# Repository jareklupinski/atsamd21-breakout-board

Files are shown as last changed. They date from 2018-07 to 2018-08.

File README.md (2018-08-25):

# atsamd21-breakout-board
A Boilerplate for the ATSAMD21 microcontroller

The ATSAMD21 is one of my favorite microcontroller families. Its low cost and ease of programming made me want to create a board that suits my project needs, so it contains RTC circuitry, an SD card slot, and a few other helpful dev touches.

The board was produced, plugged in, and did not emit magic smoke. All of the functionality hasn't been tested yet.

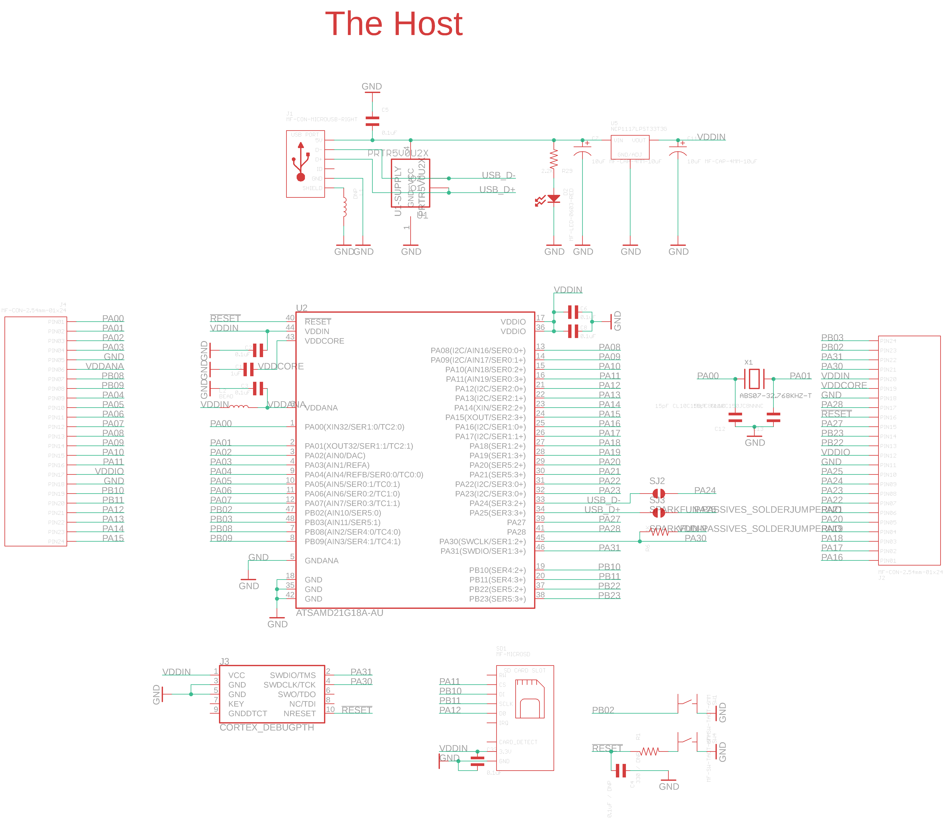
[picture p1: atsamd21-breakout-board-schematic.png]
schematic

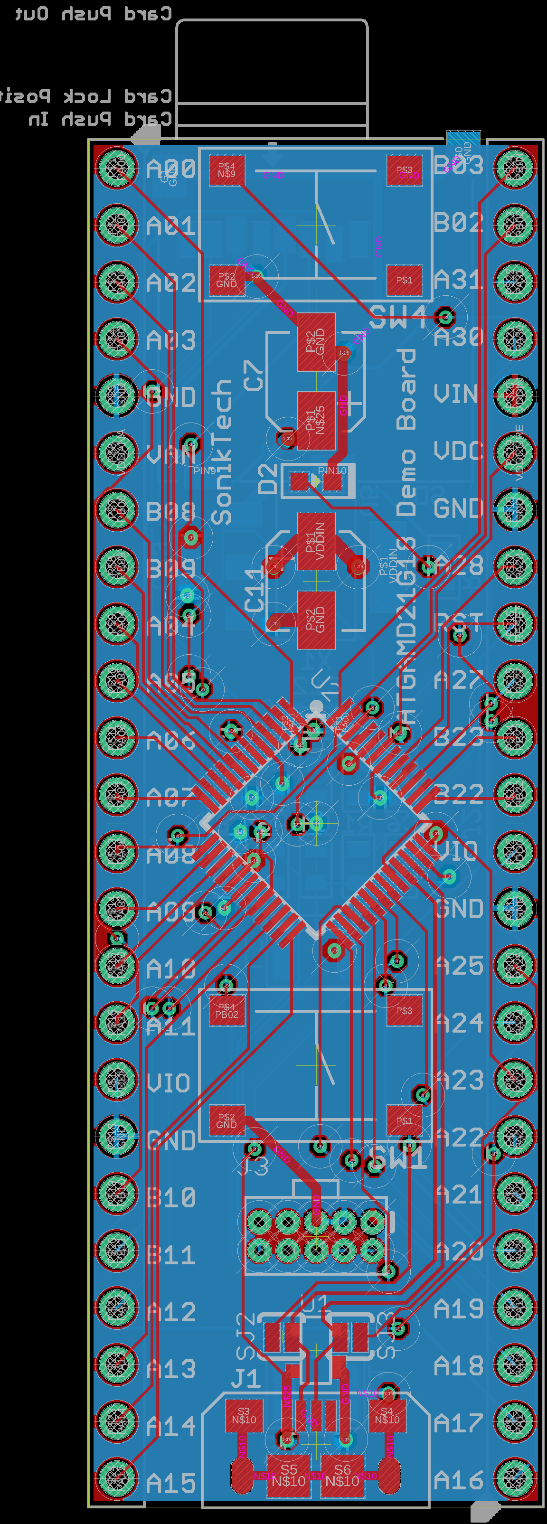
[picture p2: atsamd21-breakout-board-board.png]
board


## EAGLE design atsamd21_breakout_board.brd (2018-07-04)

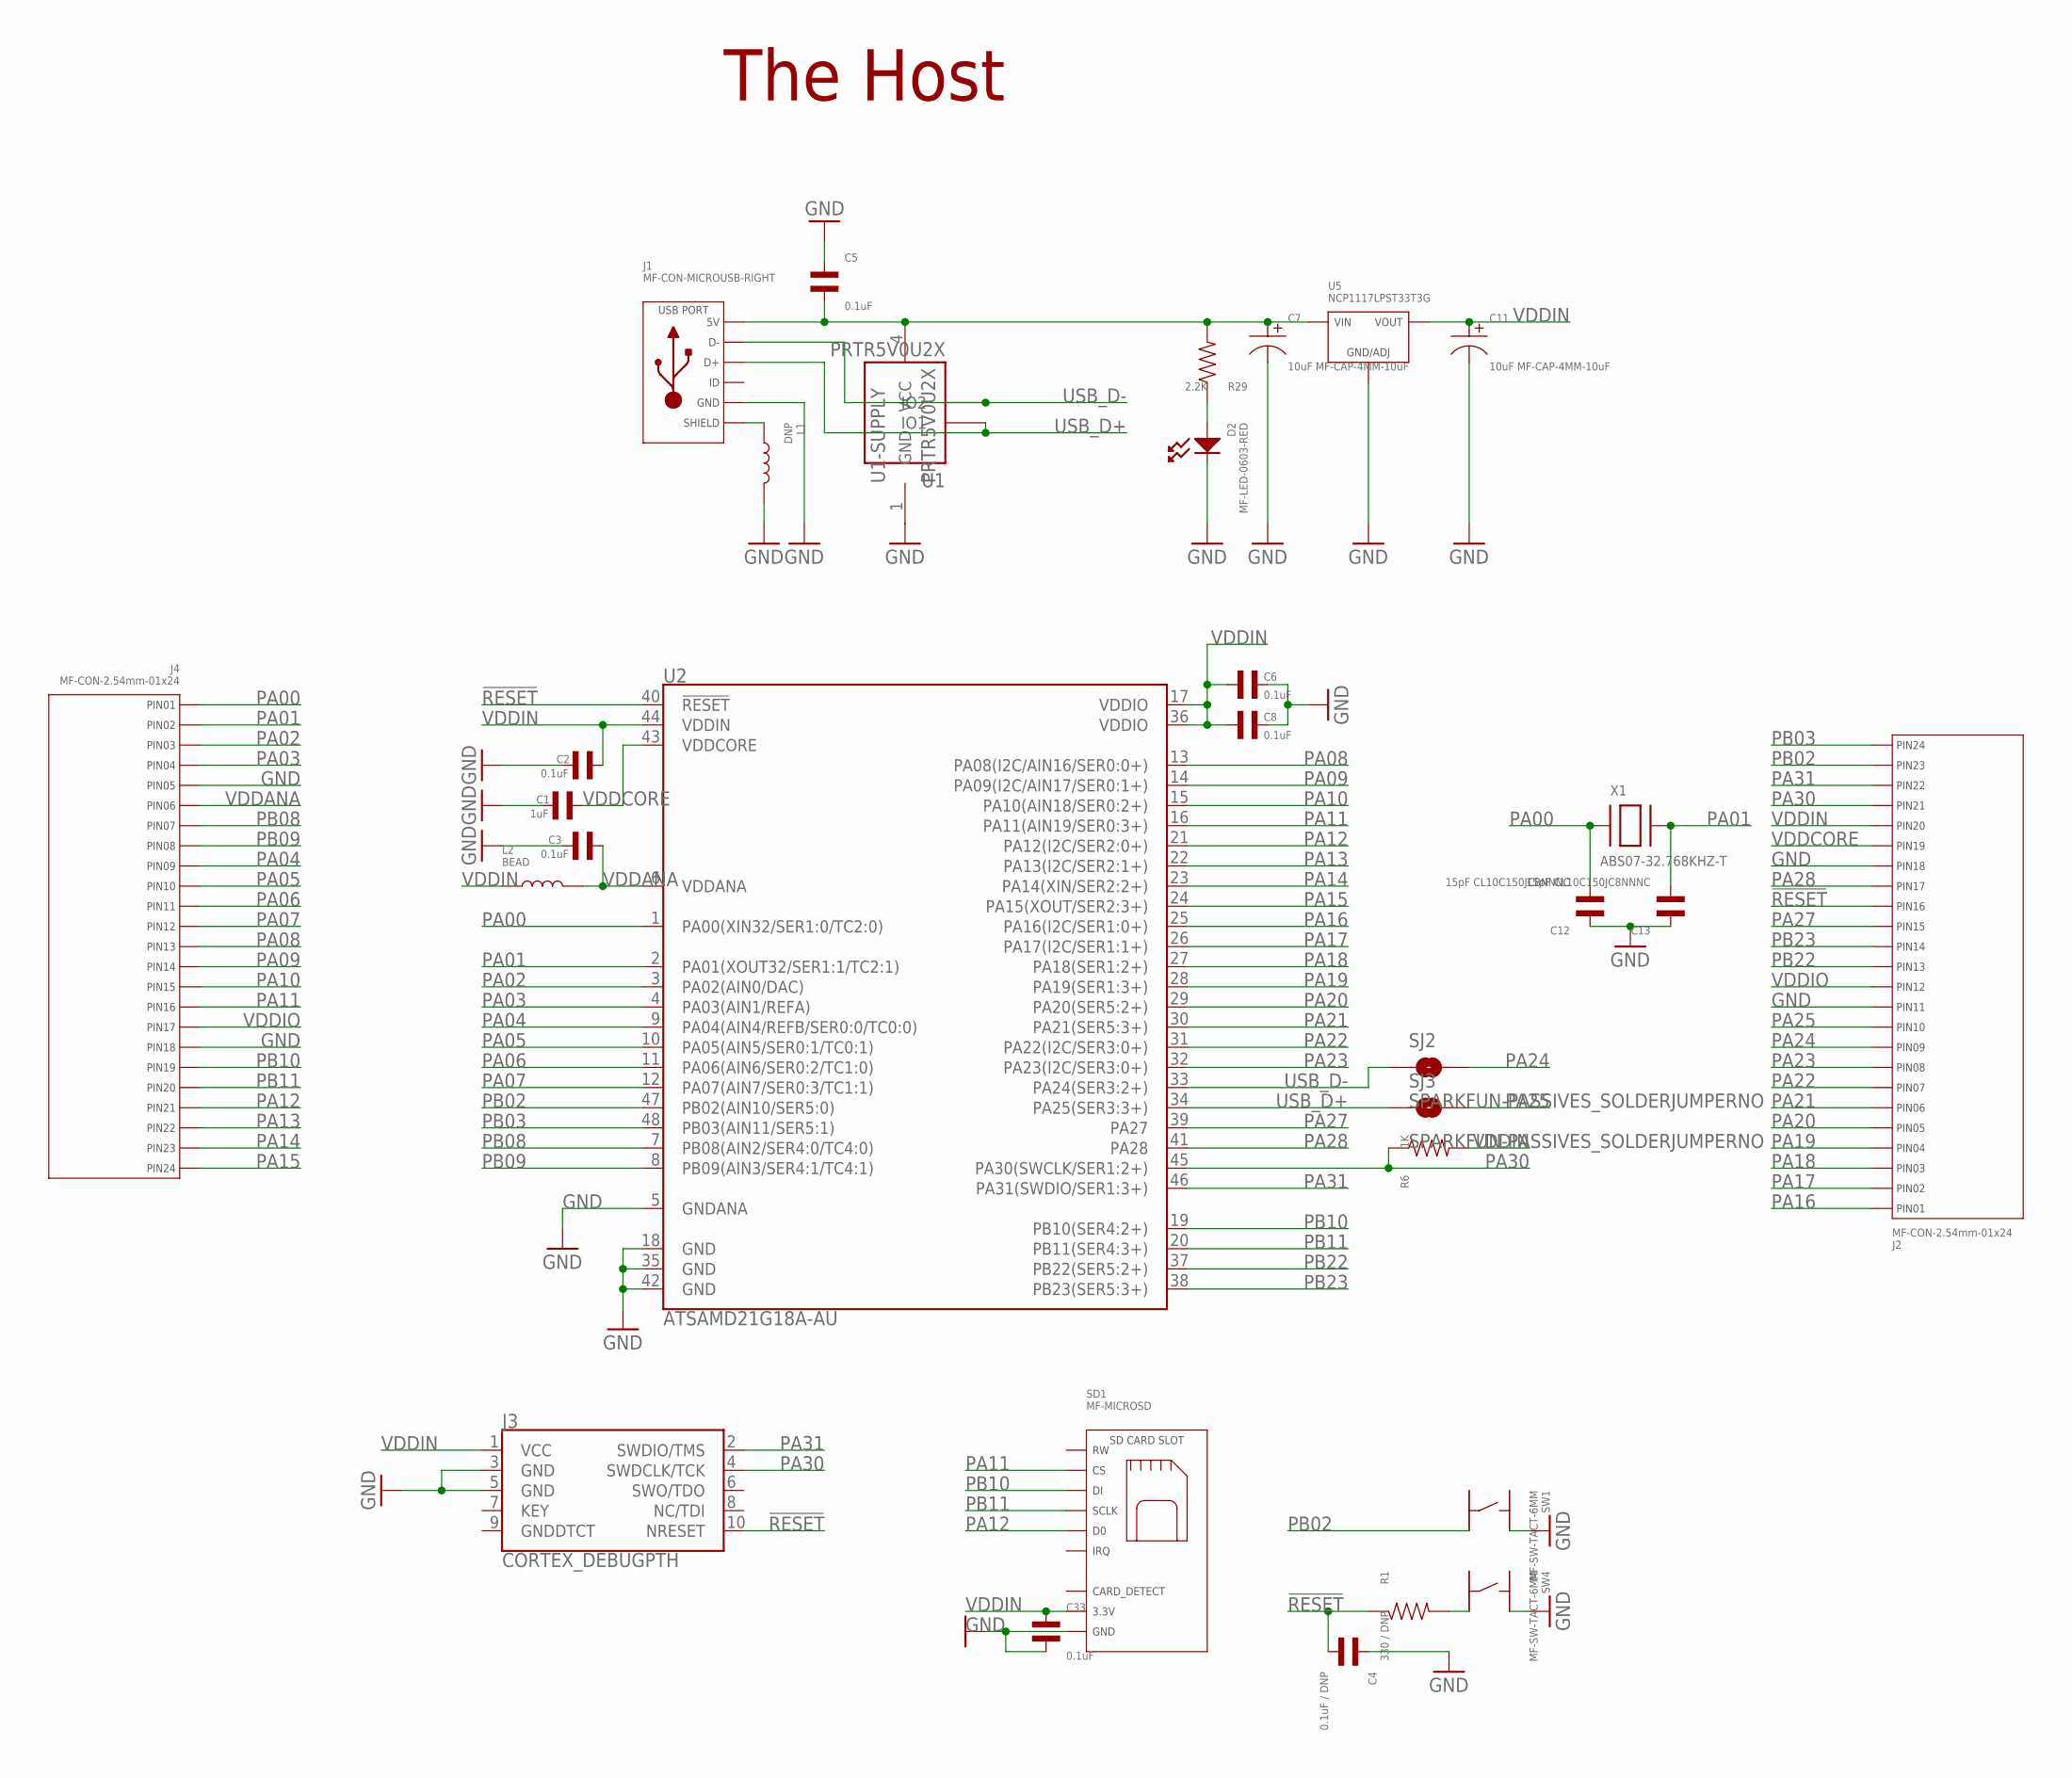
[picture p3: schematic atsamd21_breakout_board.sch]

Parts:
C1: 1uF; C0603
C2, C3, C5, C6, C8, C33: 0.1uF; C0603
C4: 0.1uF / DNP; C0603
C7, C11: 10uF MF-CAP-4MM-10uF; CP4MM
C12, C13: 15pF CL10C150JC8NNNC; C0603
D2: MF-LED-0603-RED; LED0603
J1: MF-CON-MICROUSB-RIGHT; MICROUSB-RIGHT
J2, J4: MF-CON-2.54mm-01x24; PTH_2.54MM_01X24
J3: CORTEX_DEBUGPTH; 2X5-PTH-1.27MM
L1: DNP; L1210
L2: BEAD; L1210
R1: 330 / DNP; R0603
R6: 1K; R0603
R29: 2.2K; R0603
SD1: MF-MICROSD
SJ2, SJ3: SPARKFUN-PASSIVES_SOLDERJUMPERNO; SPARKFUN-PASSIVES_SJ_2S-NO
SW1, SW4: MF-SW-TACT-6MM; TACT6MM
U1: PRTR5V0U2X; SOT-143B
U2: ATSAMD21G18A-AU; TQFP-48
U5: NCP1117LPST33T3G; SOT-223-3
X1: ABS07-32.768KHZ-T; XTAL3215

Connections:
!RESET: C4.P$2, J2.P$16 (PIN16), J3.10 (NRESET), R1.P$1, U2.40 (!RESET!)
GND: C1.P$2, C2.P$1, C3.P$1, C4.P$1, C5.P$1, C6.P$1, C7.P$2, C8.P$1, C11.P$2, C12.P$1, C13.P$1, C33.P$2, D2.CATHODE, J1.5 (GND), J2.P$11 (PIN11), J2.P$18 (PIN18), J3.3 (GND), J3.5 (GND), J4.P$5 (PIN5), J4.P$18 (PIN18), L1.P$2, SD1.G0 (GND), SD1.G1 (GND), SD1.PIN6 (GND), SW1.P$2, SW4.P$2, U1.1 (GND), U2.5 (GNDANA), U2.18 (GND), U2.35 (GND), U2.42 (GND), U5.P$2 (GND/ADJ)
unnamed: R1.P$2, SW4.P$4
unnamed: J1.S1 (SLD), J1.S2 (SLD), J1.S3 (SLD), J1.S4 (SLD), J1.S5 (SLD), J1.S6 (SLD), L1.P$1
unnamed: D2.ANODE, R29.P$1
unnamed: C5.P$2, C7.P$1, J1.1 (5V), R29.P$2, U1.4 (VCC), U5.P$4 (VIN)
PA00: C12.P$2, J4.P$1 (PIN1), U2.1 (PA00(XIN32/SER1:0/TC2:0)), X1.P$1
PA01: C13.P$2, J4.P$2 (PIN2), U2.2 (PA01(XOUT32/SER1:1/TC2:1)), X1.P$2
PA02: J4.P$3 (PIN3), U2.3 (PA02(AIN0/DAC))
PA03: J4.P$4 (PIN4), U2.4 (PA03(AIN1/REFA))
PA04: J4.P$9 (PIN9), U2.9 (PA04(AIN4/REFB/SER0:0/TC0:0))
PA05: J4.P$10 (PIN10), U2.10 (PA05(AIN5/SER0:1/TC0:1))
PA06: J4.P$11 (PIN11), U2.11 (PA06(AIN6/SER0:2/TC1:0))
PA07: J4.P$12 (PIN12), U2.12 (PA07(AIN7/SER0:3/TC1:1))
PA08: J4.P$13 (PIN13), U2.13 (PA08(I2C/AIN16/SER0:0+))
PA09: J4.P$14 (PIN14), U2.14 (PA09(I2C/AIN17/SER0:1+))
PA10: J4.P$15 (PIN15), U2.15 (PA10(AIN18/SER0:2+))
PA11: J4.P$16 (PIN16), SD1.PIN2 (CS), U2.16 (PA11(AIN19/SER0:3+))
PA12: J4.P$21 (PIN21), SD1.PIN7 (D0), U2.21 (PA12(I2C/SER2:0+))
PA13: J4.P$22 (PIN22), U2.22 (PA13(I2C/SER2:1+))
PA14: J4.P$23 (PIN23), U2.23 (PA14(XIN/SER2:2+))
PA15: J4.P$24 (PIN24), U2.24 (PA15(XOUT/SER2:3+))
PA16: J2.P$1 (PIN1), U2.25 (PA16(I2C/SER1:0+))
PA17: J2.P$2 (PIN2), U2.26 (PA17(I2C/SER1:1+))
PA18: J2.P$3 (PIN3), U2.27 (PA18(SER1:2+))
PA19: J2.P$4 (PIN4), U2.28 (PA19(SER1:3+))
PA20: J2.P$5 (PIN5), U2.29 (PA20(SER5:2+))
PA21: J2.P$6 (PIN6), U2.30 (PA21(SER5:3+))
PA22: J2.P$7 (PIN7), U2.31 (PA22(I2C/SER3:0+))
PA23: J2.P$8 (PIN8), U2.32 (PA23(I2C/SER3:0+))
PA24: J2.P$9 (PIN9), SJ2.2
PA25: J2.P$10 (PIN10), SJ3.2
PA27: J2.P$15 (PIN15), U2.39 (PA27)
PA28: J2.P$17 (PIN17), U2.41 (PA28)
PA30: J2.P$21 (PIN21), J3.4 (SWDCLK/TCK), R6.P$1, U2.45 (PA30(SWCLK/SER1:2+))
PA31: J2.P$22 (PIN22), J3.2 (SWDIO/TMS), U2.46 (PA31(SWDIO/SER1:3+))
PB02: J2.P$23 (PIN23), SW1.P$4, U2.47 (PB02(AIN10/SER5:0))
PB03: J2.P$24 (PIN24), U2.48 (PB03(AIN11/SER5:1))
PB08: J4.P$7 (PIN7), U2.7 (PB08(AIN2/SER4:0/TC4:0))
PB09: J4.P$8 (PIN8), U2.8 (PB09(AIN3/SER4:1/TC4:1))
PB10: J4.P$19 (PIN19), SD1.PIN3 (DI), U2.19 (PB10(SER4:2+))
PB11: J4.P$20 (PIN20), SD1.PIN5 (SCLK), U2.20 (PB11(SER4:3+))
PB22: J2.P$13 (PIN13), U2.37 (PB22(SER5:2+))
PB23: J2.P$14 (PIN14), U2.38 (PB23(SER5:3+))
USB_D+: J1.3 (D+), SJ3.1, U1.2 (IO1), U2.34 (PA25(SER3:3+))
USB_D-: J1.2 (D-), SJ2.1, U1.3 (IO2), U2.33 (PA24(SER3:2+))
VDDANA: C3.P$2, J4.P$6 (PIN6), L2.P$2, U2.6 (VDDANA)
VDDCORE: C1.P$1, J2.P$19 (PIN19), U2.43 (VDDCORE)
VDDIN: C2.P$2, C6.P$2, C8.P$2, C11.P$1, C33.P$1, J2.P$20 (PIN20), J3.1 (VCC), L2.P$1, R6.P$2, SD1.PIN4 (3.3V), U2.17 (VDDIO), U2.36 (VDDIO), U2.44 (VDDIN), U5.P$1 (VOUT), U5.P$3 (VOUT)
VDDIO: J2.P$12 (PIN12), J4.P$17 (PIN17)

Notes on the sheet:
The Host

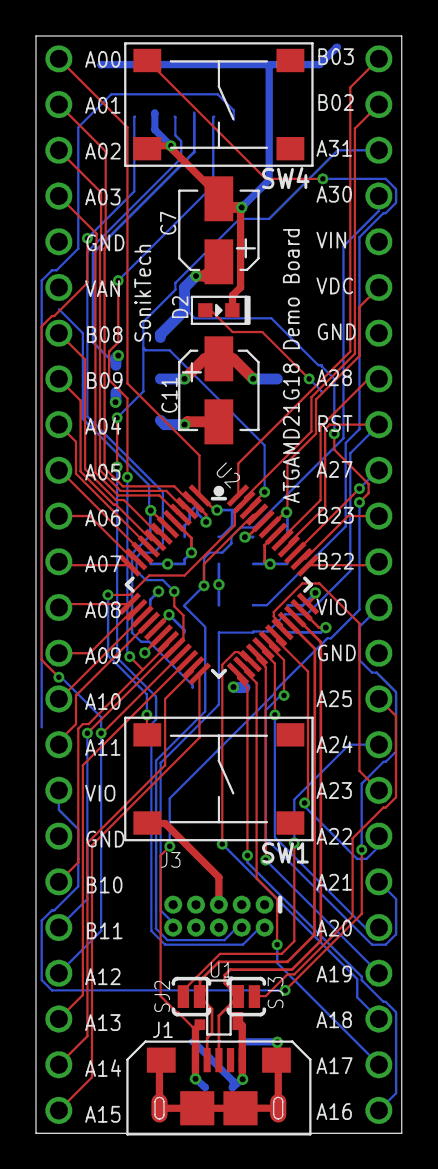
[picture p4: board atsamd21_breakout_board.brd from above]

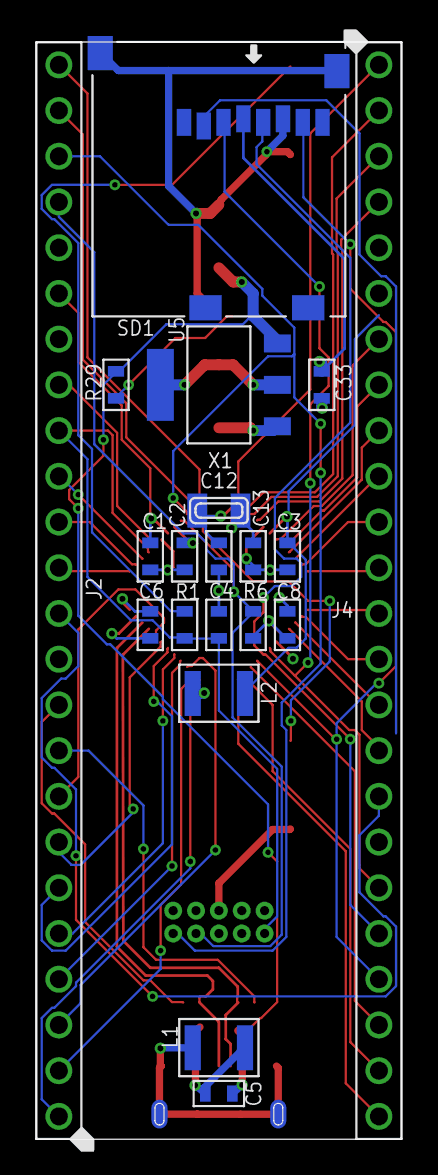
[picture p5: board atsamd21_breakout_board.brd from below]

Board: 4 copper layers, 20.3 x 60.9 mm, 31 parts (20 on the bottom side), 50 nets.

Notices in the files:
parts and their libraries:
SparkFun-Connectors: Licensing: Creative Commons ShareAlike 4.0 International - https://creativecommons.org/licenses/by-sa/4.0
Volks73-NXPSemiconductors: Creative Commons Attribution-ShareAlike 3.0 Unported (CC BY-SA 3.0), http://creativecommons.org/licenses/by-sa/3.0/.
